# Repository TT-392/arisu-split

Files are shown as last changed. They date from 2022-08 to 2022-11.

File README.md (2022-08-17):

# Warning
For the actual arisu keyboard PCB go to https://github.com/FateNozomi/arisu-pcb, this one is just an unfinished fork.

# Arisu Keyboard PCB
アリス PCB designed using KiCad. The layout is inspired by Lyn's EM7 and TGR Alice with some modification of my own.

Key differences:
- I removed the extra [B] key on the right half and shifted the [NM,.?] row to the left by 0.25U.
- Shifted the 3 keys to the right and added arrow keys.
- Tweaked the bottom so that the 1.5U keys doesn't protrude out a little.

Shifting the [NM,.?] row to the left by 0.25U required quite some work on the arrangement of keys for the right half.
As a result, this does not give the same typing experience as Lyn's EM7 and TGR Alice.
Lyn's EM7 and TGR Alice uses the home row as the center point to vertically align both halves while I used the number row instead.
Due to the nature of staggered keyboards, aligning using the number row resulted in the home row not being aligned.

Disclaimer: Use these files at your own risk.

Arisu
Arisu-top
アリス

## Gerber Files
Download the gerber files under [releases](https://github.com/FateNozomi/arisu-pcb/releases).

## Assembly
For the components required, you may refer to the bill of materials included along with the release as reference or load up the design file in KiCad.
All the components can be soldered using a regular soldering iron, though soldering the Micro USB receptacle might be the biggest hurdle.

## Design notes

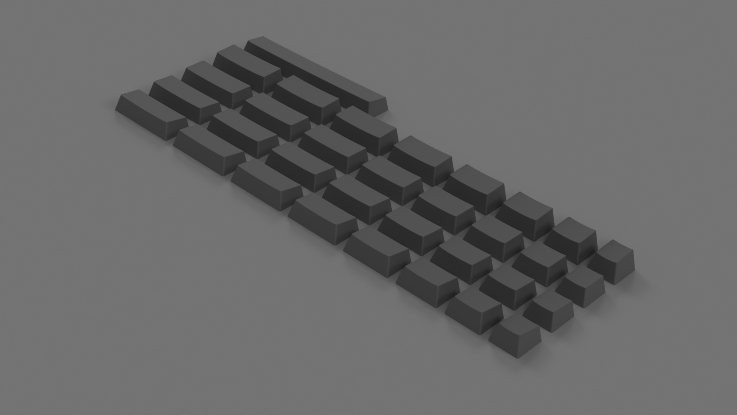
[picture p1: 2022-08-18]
3d models/cherry-mx-keycaps/img/render.png

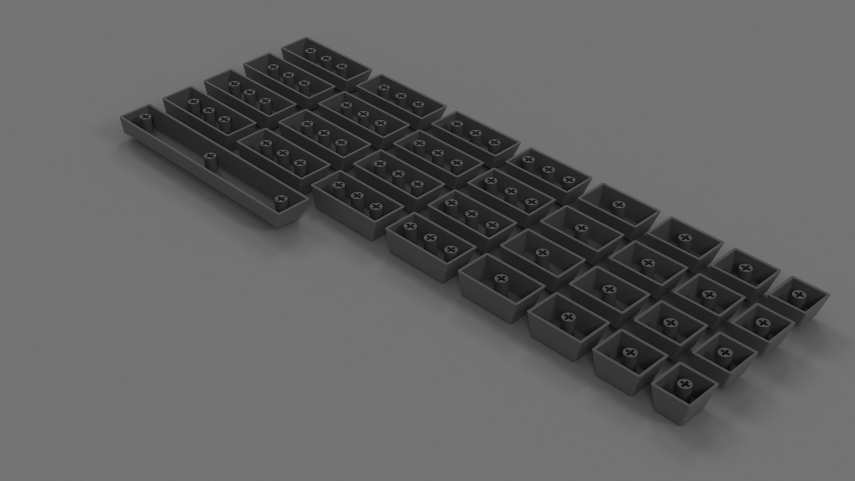
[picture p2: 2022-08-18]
3d models/cherry-mx-keycaps/img/render-bottom.png

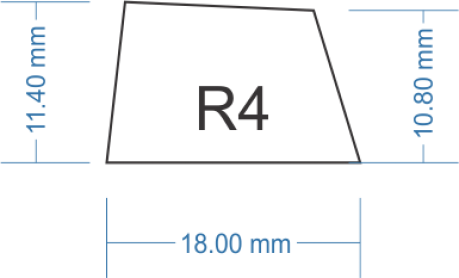
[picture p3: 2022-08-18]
3d models/cherry-mx-keycaps/ref dimensions/profile_r4_1.png

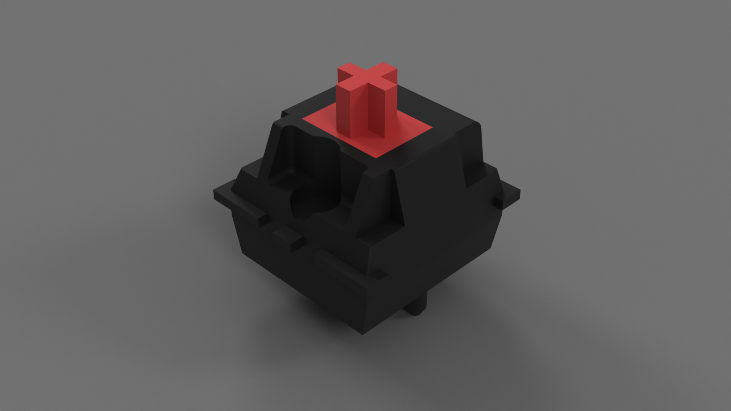
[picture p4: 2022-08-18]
3d models/cherry-mx-switch/render.png

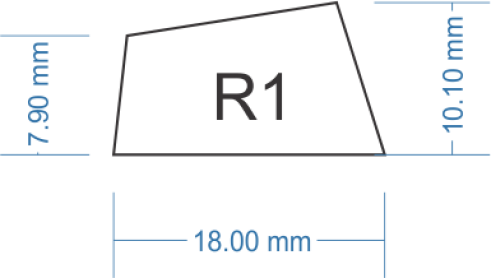
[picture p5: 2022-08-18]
3d models/cherry-mx-keycaps/ref dimensions/profile_r1_2.png

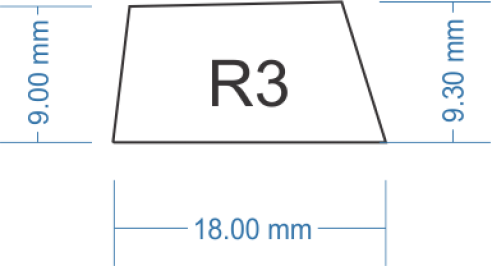
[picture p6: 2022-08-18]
3d models/cherry-mx-keycaps/ref dimensions/profile_r3_1.png

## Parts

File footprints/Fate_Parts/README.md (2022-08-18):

Forked from https://github.com/FateNozomi/Fate_Parts

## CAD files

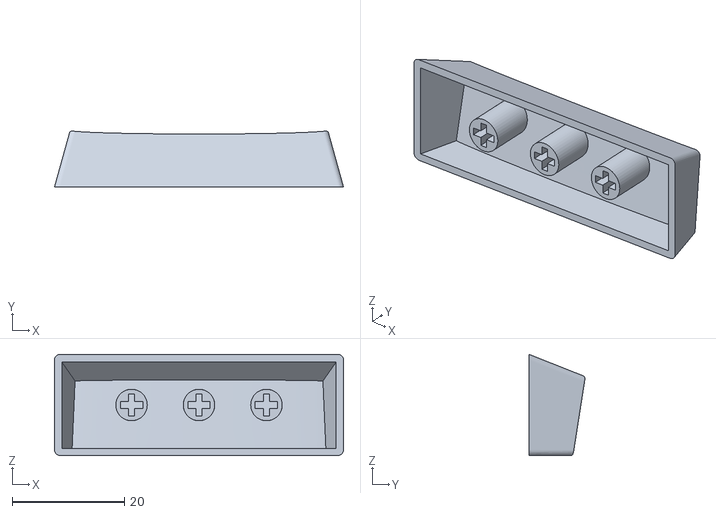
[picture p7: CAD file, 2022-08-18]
3d models/cherry-mx-keycaps/STL/1x2.75 R1.stl
51.4 x 9.91 x 18.0

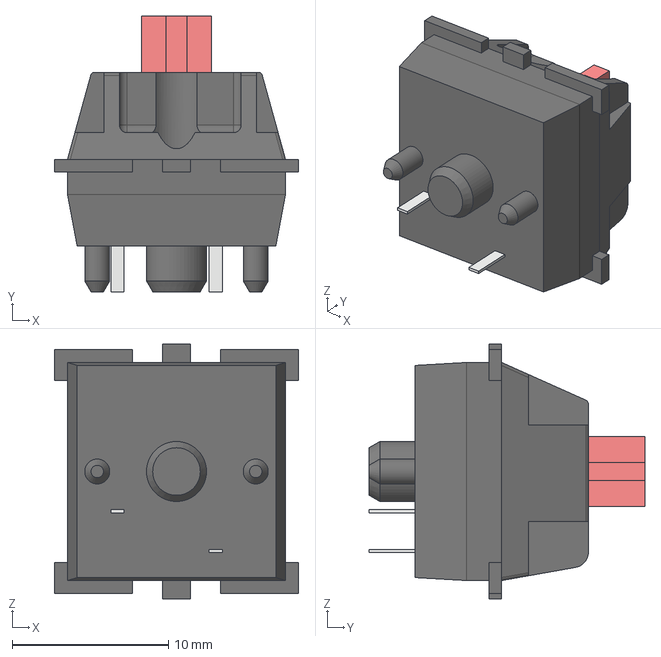
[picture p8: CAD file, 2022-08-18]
3d models/cherry-mx-switch/switch.step
15.6 x 17.7 x 16.3 mm

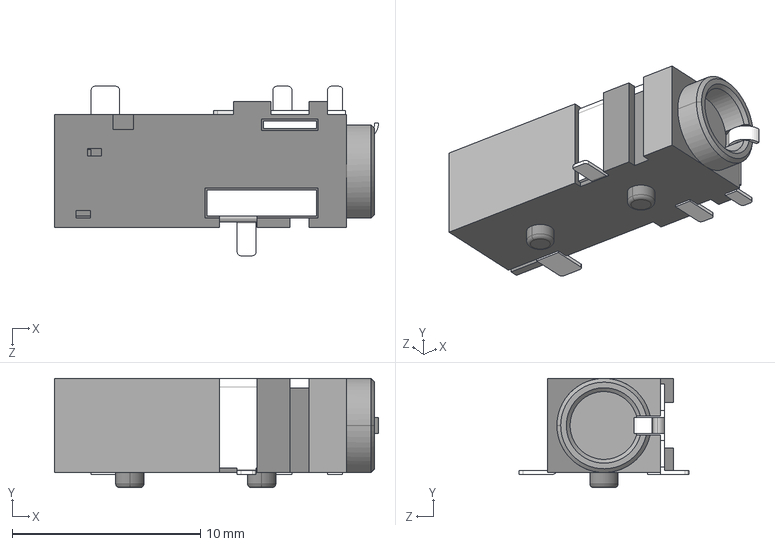
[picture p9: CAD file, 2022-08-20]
3d models/CUI_DEVICES_SJ-43514-SMT-TR.step
17.2 x 5.80 x 9.00 mm

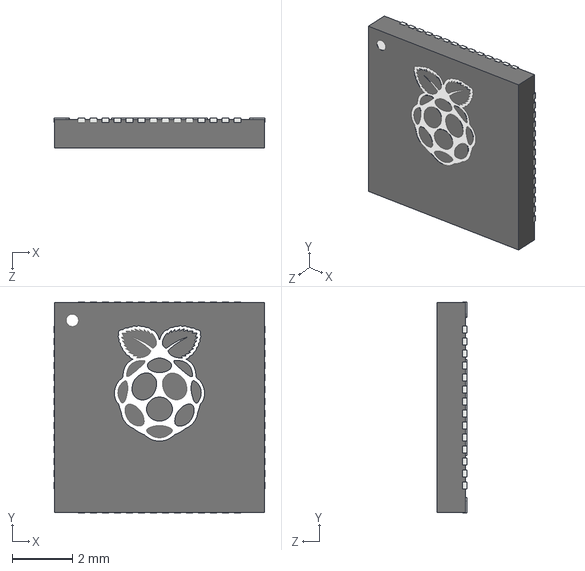
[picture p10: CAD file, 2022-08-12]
3d models/rp2040_3d_model/RP2040_QFN_PACKAGE.STEP
7.02 x 7.02 x 1.00 mm

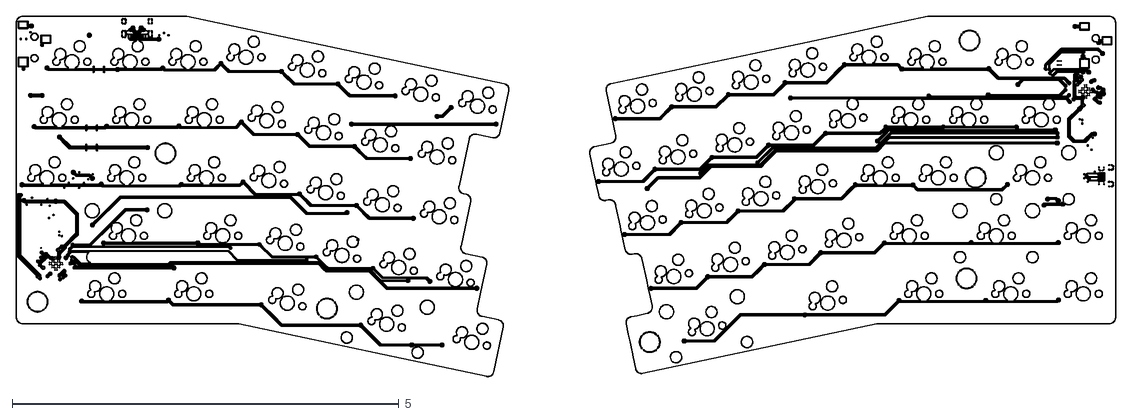
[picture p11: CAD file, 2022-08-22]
arisu.gerber/arisu-F_Cu.dxf
14.2 x 4.66

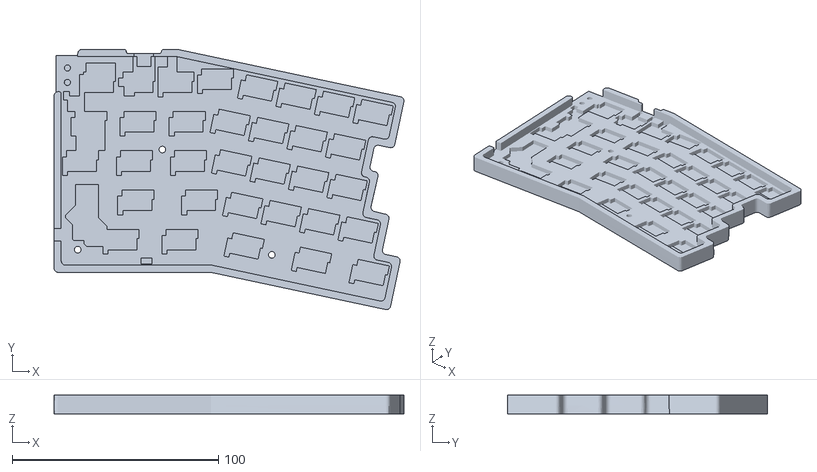
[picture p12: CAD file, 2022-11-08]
Case/case-Case_002.stl
169.5 x 126.0 x 9.00

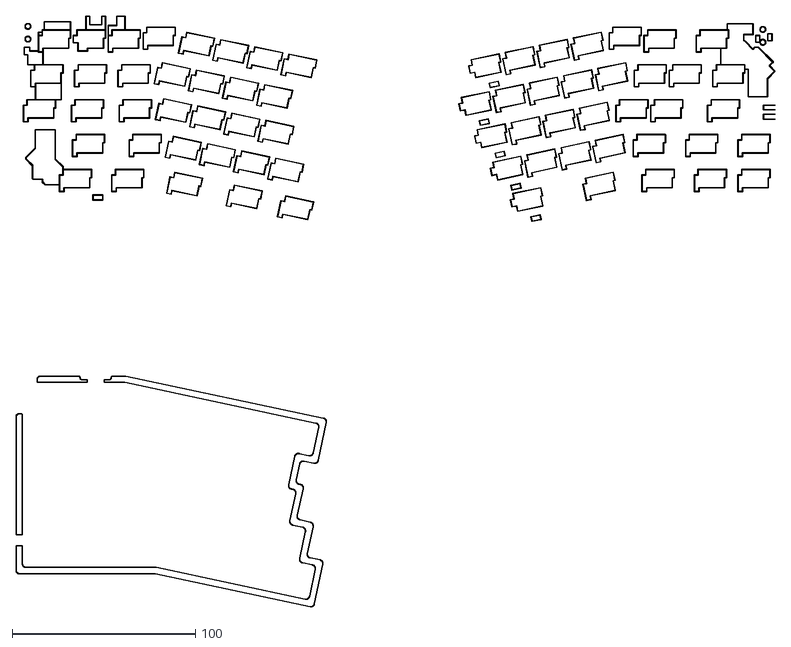
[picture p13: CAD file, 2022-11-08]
Case/kicad_export/walls.dxf
414.6 x 322.6

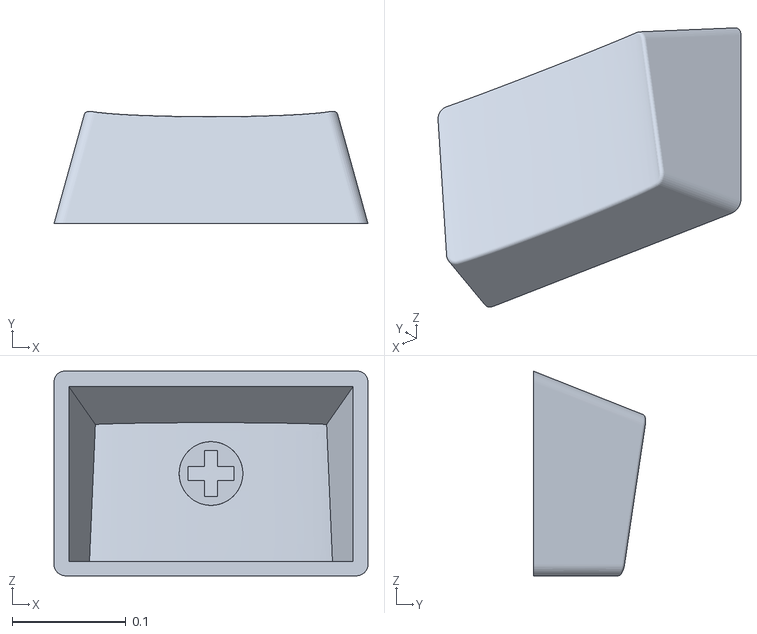
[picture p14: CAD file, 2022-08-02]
test.stl
0.276 x 0.0986 x 0.18

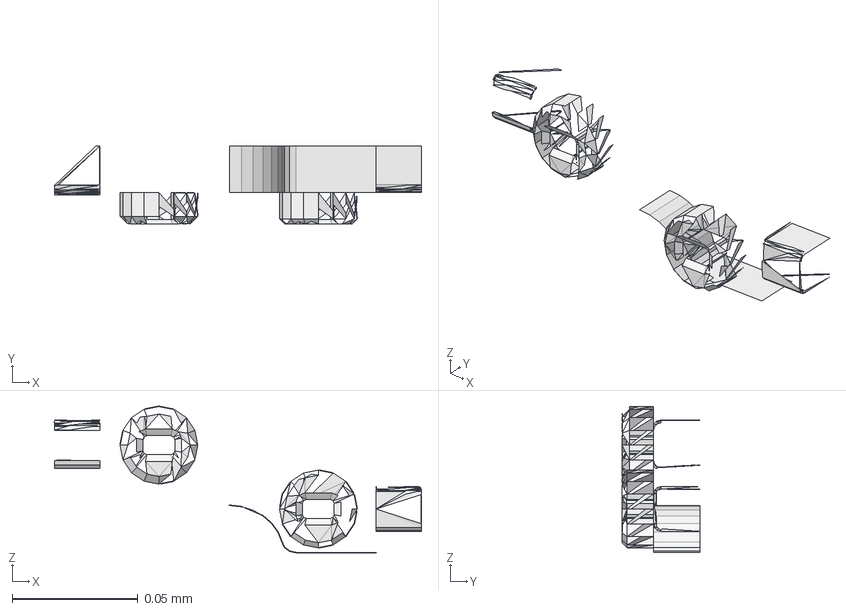
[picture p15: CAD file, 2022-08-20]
3d models/blend/kailh.stp
0.146 x 0.031 x 0.0583 mm

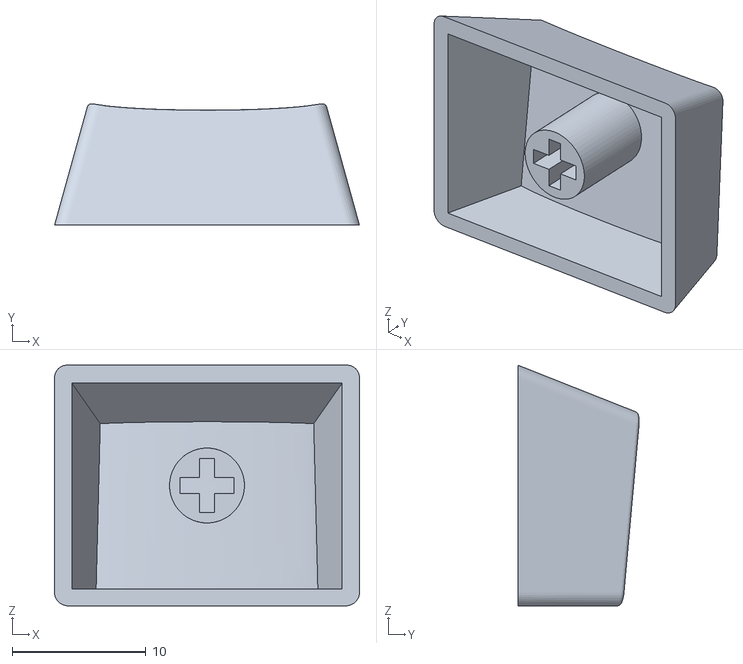
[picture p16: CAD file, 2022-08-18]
3d models/cherry-mx-keycaps/STL/1x1.25 R2.stl
22.8 x 9.07 x 18.0

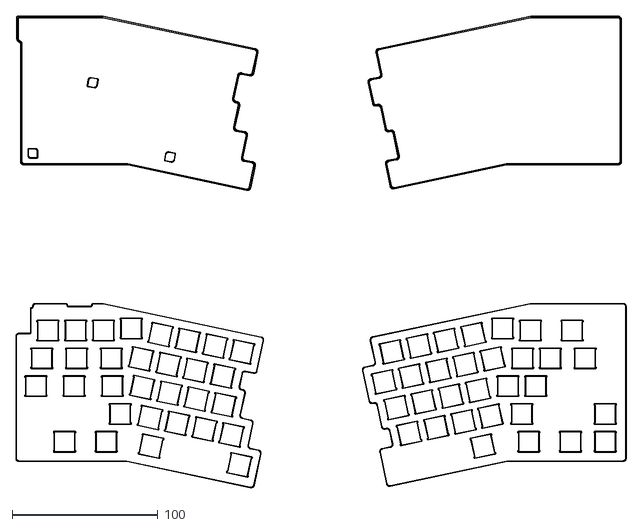
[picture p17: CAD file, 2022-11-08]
Case/kicad_export/board_tolerance.dxf
418.1 x 323.0

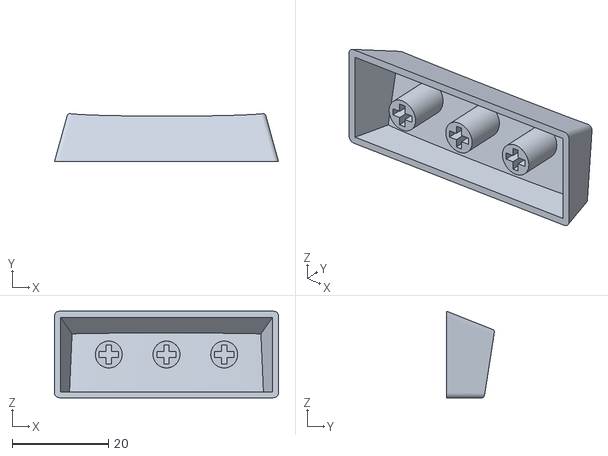
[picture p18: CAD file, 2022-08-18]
3d models/cherry-mx-keycaps/STL/1x2.5 R1.stl
46.6 x 9.90 x 18.0

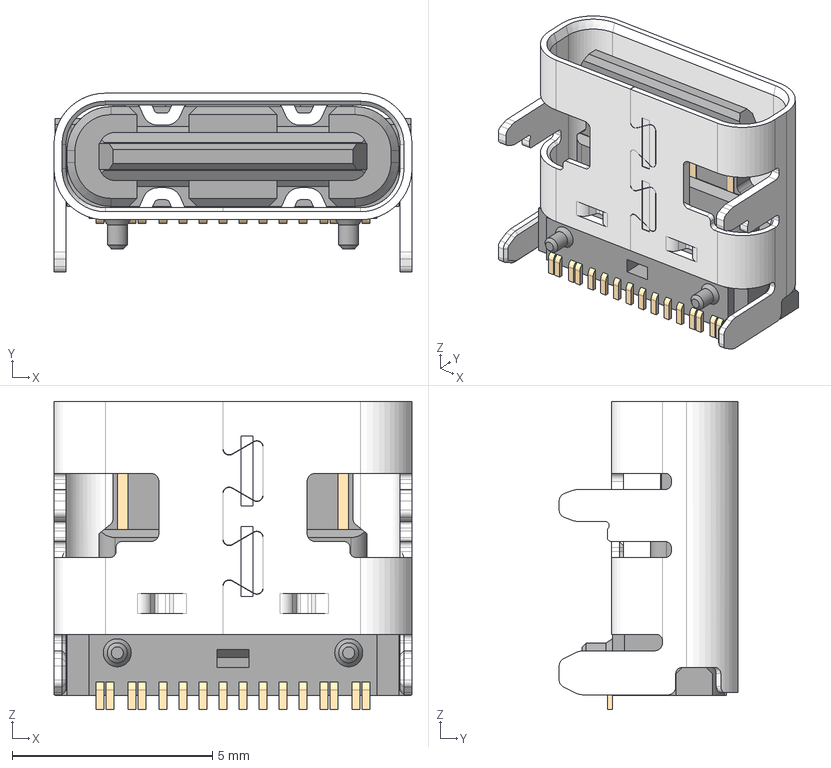
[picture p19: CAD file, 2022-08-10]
3d models/USB4105-15-A-120.stp
8.94 x 4.46 x 7.70 mm
USB4105-15-A-120_PART2
USB4105-15-A-120_PART1

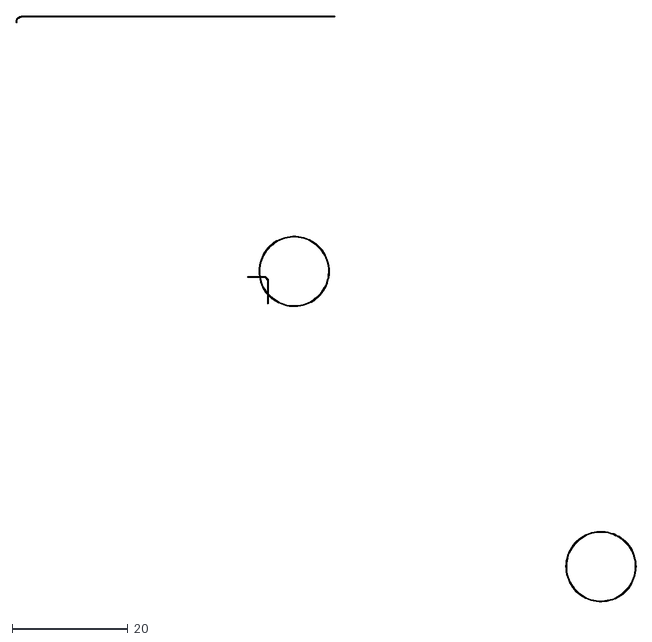
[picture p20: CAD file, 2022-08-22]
arisu.gerber/arisu-User_Eco2.dxf
107.1 x 101.1

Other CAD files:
3d models/blend/jack-Cube.obj
arisu.gerber/arisu-F_Adhesive.dxf
Case/kicad_export/cutouts.dxf
3d models/cherry-mx-keycaps/STL/1x1.5 R4.stl
3d models/10103594.stp
3d models/aluminium profile nut/nut.step
3d models/blend/jack-Cube.ply
3d models/blend/jack.blend
3d models/blend/kailh.blend
3d models/blend/kailh.stl
3d models/cherry-mx-keycaps/STL/1x1 R1.stl
3d models/cherry-mx-keycaps/STL/1x1 R2.stl
3d models/cherry-mx-keycaps/STL/1x1 R3.stl
3d models/cherry-mx-keycaps/STL/1x1 R4.stl
3d models/cherry-mx-keycaps/STL/1x1.25 R1.stl
3d models/cherry-mx-keycaps/STL/1x1.25 R3.stl
3d models/cherry-mx-keycaps/STL/1x1.25 R4.stl
3d models/cherry-mx-keycaps/STL/1x1.5 R1.stl
3d models/cherry-mx-keycaps/STL/1x1.5 R2.stl
3d models/cherry-mx-keycaps/STL/1x1.5 R3.stl
3d models/cherry-mx-keycaps/STL/1x1.75 R1.stl
3d models/cherry-mx-keycaps/STL/1x1.75 R2.stl
3d models/cherry-mx-keycaps/STL/1x1.75 R3.stl
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

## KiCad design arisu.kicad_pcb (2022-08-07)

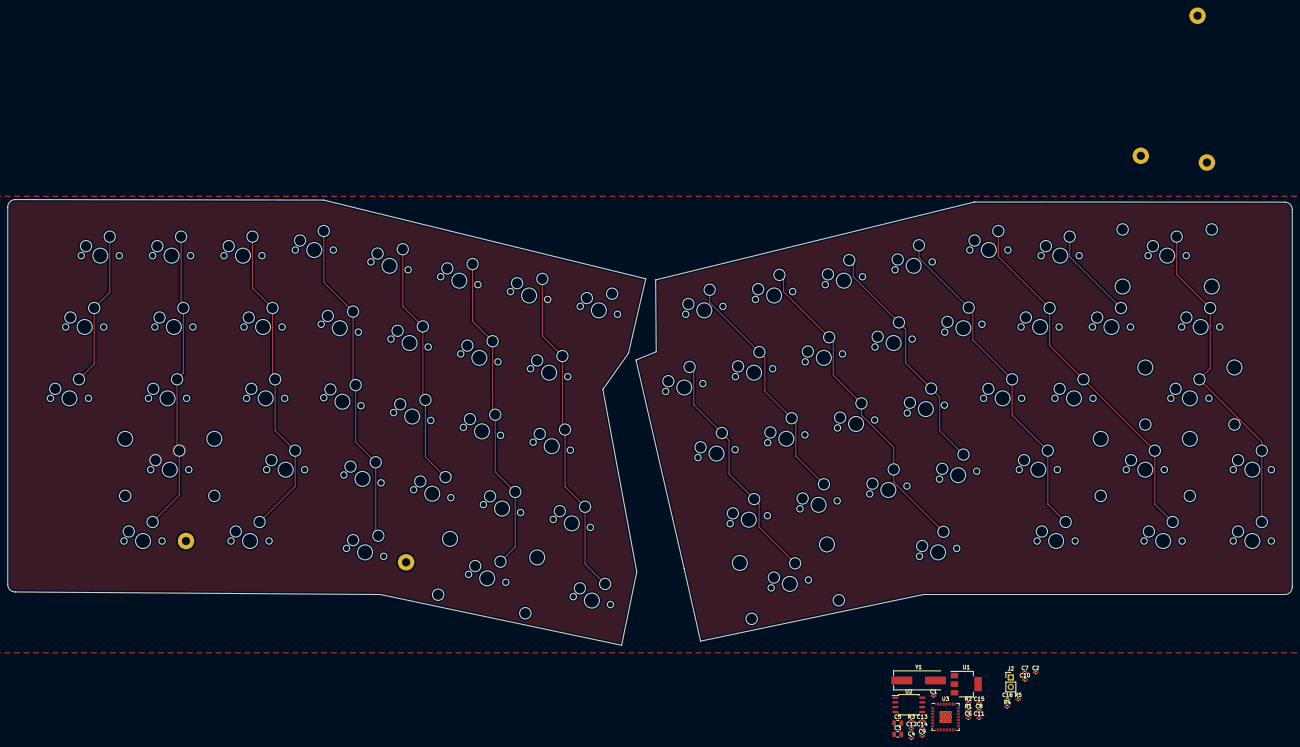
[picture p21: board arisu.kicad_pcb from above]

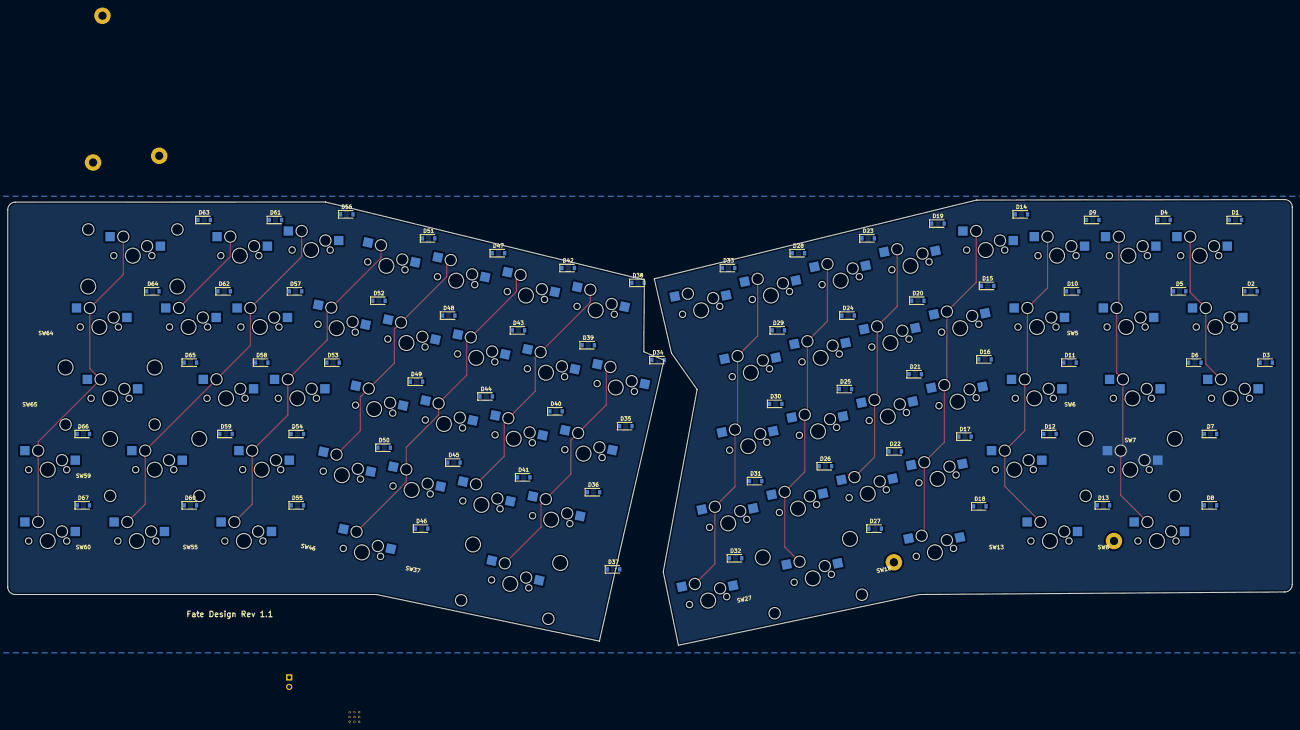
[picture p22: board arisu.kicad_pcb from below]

Board: 2 copper layers, 343.0 x 119.0 mm, 165 parts (67 on the bottom side), 108 nets.

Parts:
C1, C2: 27p; C_0402_1005Metric
C3, C5: 10u; C_0805_2012Metric
C4, C6, C7, C9, C11, C12, C13, C14, C15, C16: 100n; C_0402_1005Metric
C8, C10: 1u; C_0402_1005Metric
D1, D2, D3, D4, D5, D6, D7, D8, D9, D10, D11, D12, D13, D14, D15, D16, D17, D18, D19, D20, D21, D22, D23, D24, D25, D26, D27, D28, D29, D30, D31, D32, D33, D34, D35, D36, D37, D38, D39, D40, D41, D42, D43, D44, D45, D46, D47, D48, D49, D50, D51, D52, D53, D54, D55, D56, D57, D58, D59, D60, D61, D62, D63, D64, D65, D66, D67: D; D_SOD-123
H1, H2, H4, H6, H7: MountingHole; MountingHole_2.2mm_M2_Pad
J2: Conn_01x02; PinHeader_1x02_P2.54mm_Vertical
R1, R3: 1k; C_0402_1005Metric
R2: DNF; C_0402_1005Metric
R4, R5: 27; C_0402_1005Metric
SW1, SW2, SW3, SW4, SW9, SW10, SW11, SW12, SW14, SW15, SW16, SW17, SW19, SW20, SW21, SW22, SW23, SW24, SW25, SW26, SW28, SW29, SW30, SW31, SW32, SW33, SW34, SW35, SW36, SW38, SW39, SW40, SW41, SW42, SW43, SW44, SW45, SW47, SW48, SW49, SW50, SW51, SW52, SW53, SW54, SW56, SW57, SW58, SW61, SW62, SW66, SW67: SW_Push; SW_Cherry_MX_1.00u_PCB_Socket
SW5, SW8, SW13, SW18, SW46, SW55, SW60, SW64: SW_Push; SW_Cherry_MX_1.50u_PCB_Socket
SW6: SW_Push; SW_Cherry_MX_1.75u_PCB_Socket
SW7, SW65: SW_Push; SW_Cherry_MX_2.25u_PCB_Socket_ReversedStabilizers
SW27, SW59: SW_Push; SW_Cherry_MX_2.00u_PCB_Socket_ReversedStabilizers
SW37: SW_Push; SW_Cherry_MX_2.75u_PCB_Socket_ReversedStabilizers
SW63: SW_Push; SW_Cherry_MX_2.00u_PCB_Socket
U1: NCP1117-3.3_SOT223; SOT-223-3_TabPin2
U2: W25Q128JVS; SOIC-8_5.23x5.23mm_P1.27mm
U3: RP2040; RP2040-QFN-56
Y1: ABLS-12.000MHZ-B4-T; Crystal_SMD_HC49-US

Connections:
+3V3_L: C4.1, C5.1, C9.1, C10.1, C11.1, C12.1, C13.1, C14.1, C15.1, C16.1, R2.1, U1.2 (VO), U2.8 (VCC), U3.1 (IOVDD), U3.10 (IOVDD), U3.22 (IOVDD), U3.26 (RUN), U3.33 (IOVDD), U3.42 (IOVDD), U3.43 (ADC_AVDD), U3.44 (VREG_IN), U3.48 (USB_VDD), U3.49 (IOVDD)
+5R: C3.1, U1.3 (VI)
/Left/matrixL/col0: SW1.1, SW2.1, SW3.1
/Left/matrixL/col1: SW4.1, SW5.1, SW6.1, SW7.1, SW8.1
/Left/matrixL/col2: SW9.1, SW10.1, SW11.1, SW12.1, SW13.1
/Left/matrixL/col3: SW14.1, SW15.1, SW16.1, SW17.1, SW18.1
/Left/matrixL/col4: SW19.1, SW20.1, SW21.1, SW22.1, SW33.1
/Left/matrixL/col5: SW23.1, SW24.1, SW25.1, SW26.1, SW27.1
/Left/matrixL/col6: SW28.1, SW29.1, SW30.1, SW31.1, SW32.1
/Left/matrixL/row0: D1.1 (K), D4.1 (K), D9.1 (K), D14.1 (K), D19.1 (K), D23.1 (K), D28.1 (K)
/Left/matrixL/row1: D2.1 (K), D5.1 (K), D10.1 (K), D15.1 (K), D20.1 (K), D24.1 (K), D29.1 (K)
/Left/matrixL/row2: D3.1 (K), D6.1 (K), D11.1 (K), D16.1 (K), D21.1 (K), D25.1 (K), D30.1 (K)
/Left/matrixL/row3: D7.1 (K), D12.1 (K), D17.1 (K), D22.1 (K), D26.1 (K), D31.1 (K)
/Left/matrixL/row4: D8.1 (K), D13.1 (K), D18.1 (K), D27.1 (K), D32.1 (K), D33.1 (K)
/Right/1V1: C6.1, C7.1, C8.1, U3.23 (DVDD), U3.45 (VREG_VOUT), U3.50 (DVDD)
/Right/QSPI_SCLK: U2.6 (CLK), U3.52 (QSPI_SCLK)
/Right/QSPI_SD0: U2.5 (DI(IO0)), U3.53 (QSPI_SD0)
/Right/QSPI_SD1: U2.2 (DO(IO1)), U3.55 (QSPI_SD1)
/Right/QSPI_SD2: U2.3 (IO2), U3.54 (QSPI_SD2)
/Right/QSPI_SD3: U2.7 (IO3), U3.51 (QSPI_SD3)
/Right/QSPI_SS: R1.1, R2.2, U2.1 (~CS), U3.56 (QSPI_SS)
/Right/XIN: C1.1, U3.20 (XIN), Y1.1
/Right/XOUT: R3.1, U3.21 (XOUT)
/Right/matrixR/col0: SW34.1, SW35.1, SW36.1, SW37.1, U3.2 (GPIO0)
/Right/matrixR/col1: SW38.1, SW39.1, SW40.1, SW41.1, U3.3 (GPIO1)
/Right/matrixR/col2: SW42.1, SW43.1, SW44.1, SW45.1, SW46.1, U3.4 (GPIO2)
/Right/matrixR/col3: SW47.1, SW48.1, SW49.1, SW50.1, U3.5 (GPIO3)
/Right/matrixR/col4: SW51.1, SW52.1, SW53.1, SW54.1, SW55.1, U3.6 (GPIO4)
/Right/matrixR/col5: SW56.1, SW57.1, SW58.1, SW59.1, SW60.1, U3.7 (GPIO5)
/Right/matrixR/col6: SW61.1, SW62.1, U3.8 (GPIO6)
/Right/matrixR/col7: SW63.1, SW64.1, SW65.1, SW66.1, SW67.1, U3.9 (GPIO7)
/Right/matrixR/row0: D38.1 (K), D42.1 (K), D47.1 (K), D51.1 (K), D56.1 (K), D61.1 (K), D63.1 (K), U3.11 (GPIO8)
/Right/matrixR/row1: D34.1 (K), D39.1 (K), D43.1 (K), D48.1 (K), D52.1 (K), D57.1 (K), D62.1 (K), D64.1 (K), U3.12 (GPIO9)
/Right/matrixR/row2: D35.1 (K), D40.1 (K), D44.1 (K), D49.1 (K), D53.1 (K), D58.1 (K), D65.1 (K), U3.13 (GPIO10)
/Right/matrixR/row3: D36.1 (K), D41.1 (K), D45.1 (K), D50.1 (K), D54.1 (K), D59.1 (K), D66.1 (K), U3.14 (GPIO11)
/Right/matrixR/row4: D37.1 (K), D46.1 (K), D55.1 (K), D60.1 (K), D67.1 (K), U3.15 (GPIO12)
/Right/~USB_BOOT: J2.1, R1.2
GND: C1.2, C2.2, C3.2, C4.2, C5.2, C6.2, C7.2, C8.2, C9.2, C10.2, C11.2, C12.2, C13.2, C14.2, C15.2, C16.2, J2.2, U1.1 (GND), U2.4 (GND), U3.19 (TESTEN), U3.57 (GND)
unnamed: C2.1, R3.2, Y1.2
unnamed: D1.2 (A), SW1.2
unnamed: D2.2 (A), SW2.2
unnamed: D3.2 (A), SW3.2
unnamed: D4.2 (A), SW4.2
unnamed: D5.2 (A), SW5.2
unnamed: D6.2 (A), SW6.2
unnamed: D7.2 (A), SW7.2
unnamed: D8.2 (A), SW8.2
unnamed: D9.2 (A), SW9.2
unnamed: D10.2 (A), SW10.2
unnamed: D11.2 (A), SW11.2
unnamed: D12.2 (A), SW12.2
unnamed: D13.2 (A), SW13.2
unnamed: D14.2 (A), SW14.2
unnamed: D15.2 (A), SW15.2
unnamed: D16.2 (A), SW16.2
unnamed: D17.2 (A), SW17.2
unnamed: D18.2 (A), SW18.2
unnamed: D19.2 (A), SW19.2
unnamed: D20.2 (A), SW20.2
unnamed: D21.2 (A), SW21.2
unnamed: D22.2 (A), SW22.2
unnamed: D23.2 (A), SW23.2
unnamed: D24.2 (A), SW24.2
unnamed: D25.2 (A), SW25.2
unnamed: D26.2 (A), SW26.2
unnamed: D27.2 (A), SW27.2
unnamed: D28.2 (A), SW28.2
unnamed: D29.2 (A), SW29.2
unnamed: D30.2 (A), SW30.2
unnamed: D31.2 (A), SW31.2
unnamed: D32.2 (A), SW32.2
unnamed: D33.2 (A), SW33.2
unnamed: D34.2 (A), SW34.2
unnamed: D35.2 (A), SW35.2
unnamed: D36.2 (A), SW36.2
unnamed: D37.2 (A), SW37.2
unnamed: D38.2 (A), SW38.2
unnamed: D39.2 (A), SW39.2
unnamed: D40.2 (A), SW40.2
unnamed: D41.2 (A), SW41.2
unnamed: D42.2 (A), SW42.2
unnamed: D43.2 (A), SW43.2
unnamed: D44.2 (A), SW44.2
unnamed: D45.2 (A), SW45.2
unnamed: D46.2 (A), SW46.2
unnamed: D47.2 (A), SW47.2
unnamed: D48.2 (A), SW48.2
unnamed: D49.2 (A), SW49.2
unnamed: D50.2 (A), SW50.2
unnamed: D51.2 (A), SW51.2
unnamed: D52.2 (A), SW52.2
unnamed: D53.2 (A), SW53.2
unnamed: D54.2 (A), SW54.2
unnamed: D55.2 (A), SW55.2
unnamed: D56.2 (A), SW56.2
unnamed: D57.2 (A), SW57.2
unnamed: D58.2 (A), SW58.2
unnamed: D59.2 (A), SW59.2
unnamed: D60.2 (A), SW60.2
unnamed: D61.2 (A), SW61.2
unnamed: D62.2 (A), SW62.2
unnamed: D63.2 (A), SW63.2
unnamed: D64.2 (A), SW64.2
unnamed: D65.2 (A), SW65.2
unnamed: D66.2 (A), SW66.2
unnamed: D67.2 (A), SW67.2
unnamed: R4.2, U3.47 (USB_DP)
unnamed: R5.2, U3.46 (USB_DM)

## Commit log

2019-01-27 Move all footprints F.SilkS label to B.SilkS
2019-01-28 Add Buzzer_AST1109MLTRQ footprint
2019-01-28 Add Komi art footprint
2019-06-04 Add HRO TYPE-C-31-M-12 footprint
2019-06-07 Add Kailh PCB Socket 1.00u and 2.00u footprint
2019-06-10 Define Kailh PCB Socket 1.00u and 2.00u courtyard
2019-10-23 Add centered MX 1.00u, 2.00u, 6.25u and 7.00u footprints
2019-11-02 Remove Miscellaneous footprints
2019-11-02 Add SWD and I2C headers
2020-10-20 Update symbol library to 5.1.7 USB_B_Micro USBLC6-25C6 ATmega32U4-AU
    [arisu.sch, matrix.sch]
2020-10-20 Update MX_Switch footprints from Fate_Parts
    [arisu.kicad_pcb, arisu.sch, matrix.sch]
2022-07-31 Convert to new kicad format
    [arisu.kicad_pcb, arisu.kicad_sch, matrix.kicad_sch]
2022-07-31 Update 3d models
    [arisu.kicad_pcb, arisu.kicad_sch, matrix.kicad_sch]
2022-08-02 new layout
    [arisu.kicad_pcb, arisu.kicad_sch, matrix.kicad_sch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]
2022-08-03 scripting tests
    [arisu.kicad_pcb, arisu.kicad_sch, matrix.kicad_sch]
2022-08-03 Convert stl files to step
2022-08-04 Add RP2040
    [arisu.kicad_pcb, arisu.kicad_sch]
2022-08-04 Remove some more old files
    [arisu.sch, matrix.sch]
2022-08-04 Split the keyboard into multiple files, give both sides a micro, and added 1 of the 2 jack circuits
    [Left.kicad_sch, Right.kicad_sch, arisu.kicad_pcb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]
2022-08-07 Hot pluggable trrs
    [Left.kicad_sch, Right.kicad_sch, arisu.kicad_sch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]
2022-08-07 Added socketed versions of some keycaps, and center keycaps
2022-08-07 No more erc errors + centering and socketing of switches
    [Left.kicad_sch, arisu.kicad_pcb, arisu.kicad_sch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]
2022-08-10 Add second micro back in, and added some footprints
    [Left.kicad_sch, Right.kicad_sch, USB4105-15-A-120.stp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]
2022-08-12 Schematic mostly finished
    [10103594.stp, Left.kicad_sch, RP2040_QFN_PACKAGE.STEP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]
2022-08-12 Some layout
    [arisu.kicad_sch, jack.kicad_sch]
2022-08-17 Removed stabilizer holes from a footprint
2022-08-17 more layout, and some 3d files
    [Left.kicad_sch, Right.kicad_sch, arisu.kicad_sch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]
2022-08-20 Finished layout (for now), board outline, and new trrs jacks
    [CUI_DEVICES_SJ-43514-SMT-TR.step, Left.kicad_sch, arisu.kicad_sch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]
2022-08-20 Moved some stuff´
    [1x1 R1.stl, 1x1 R2.stl, 1x1 R3.stl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]
2022-08-20 Moved footprints and 3d models into directories
    [10103594.stp, CUI_DEVICES_SJ-43514-SMT-TR.step, RP2040_QFN_PACKAGE.STEP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]
2022-08-22 Started work on e.eco case cutout
    [Left.kicad_sch, Right.kicad_sch, arisu-B_Adhesive.dxf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]
2022-08-24 Add cutout drawings
    [Right.kicad_sch, arisu.kicad_sch]
2022-10-17 plates added
    [arisu.kicad_sch, matrixR.kicad_sch]
2022-11-03 expand plate edges
2022-11-05 left side of keyboard finished for the time being
    [Left.kicad_sch, Plate left.kicad_sch, Right.kicad_sch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]
2022-11-08 Left side case created in blender
    [Left.kicad_sch, Right.kicad_sch, arisu.kicad_sch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]
2022-11-08 temp commit, squash with next
    [arisu.kicad_sch]
2022-11-10 Fix left shift footprint, add stabilizer cutouts back in
    [arisu.kicad_sch, matrixL.kicad_sch]
2022-11-10 Make board outlines thin
    [arisu-B_Cu.gbl, arisu-B_Mask.gbs, arisu-B_Silkscreen.gbo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]
2022-11-10 Left side gerbers generated
    [Plate left.kicad_sch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]
2022-11-13 Add arisu logo and generate plate gerbers again
    [arisu-B_Cu.gbl, arisu-B_Mask.gbs, arisu-B_Silkscreen.gbo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]
2022-11-13 Regenerate pcb_left gerbers
    [arisu-B_Cu.gbl, arisu-B_Mask.gbs, arisu-B_Silkscreen.gbo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]

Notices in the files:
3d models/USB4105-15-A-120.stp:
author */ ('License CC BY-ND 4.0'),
